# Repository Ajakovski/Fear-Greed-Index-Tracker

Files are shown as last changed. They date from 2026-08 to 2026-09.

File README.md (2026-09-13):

<div align = "center">

# A Wi-Fi powered Fear & Greed Index Tracker

<p>

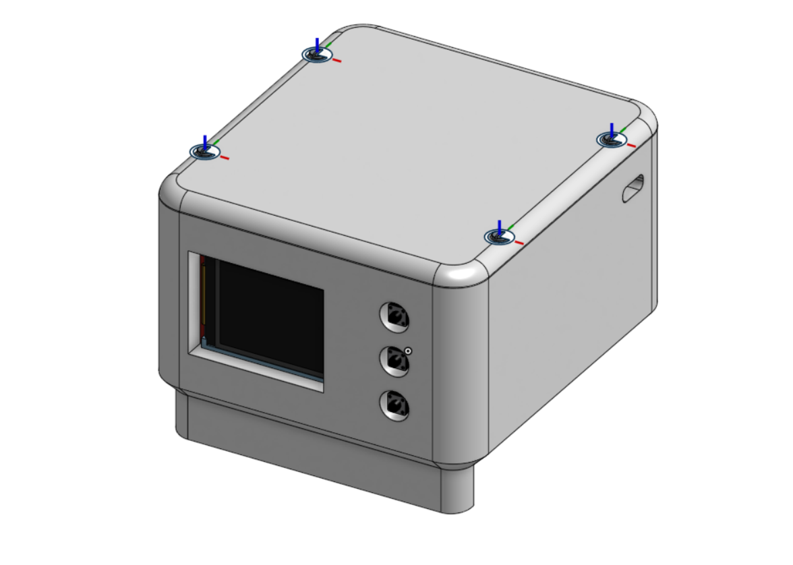
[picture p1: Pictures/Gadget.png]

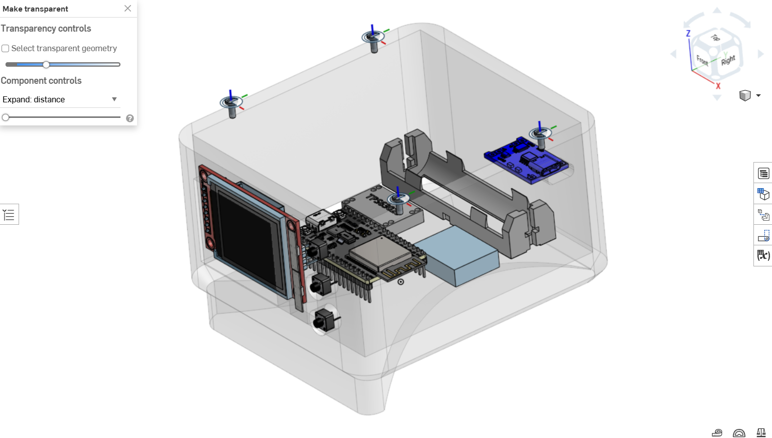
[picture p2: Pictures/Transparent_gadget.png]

</p>

### _Live tracker on your desk displaying how the market *FEELS*._

</div>

---
## Motivation

<div align = "center">

Have you ever felt overwhelmed by the sheer amount of work that you have limiting your counciousness that you **HAVE** to check the US stock market because your whole childhood lifesavings could be **GONE** thanks to **YOUR** irresponsible trading???

</div>

> _If you said yes..._

<div align = "center">

***WORRY NO MORE!!!***

------------------------------------------- ***THE FEAR & GREED INDEX TRACKER*** --------------------------------------------

</div>

**The gadget on your working desk that you did not know you ever needed.**

Always have a quick look on the current state of the market while working on something else giving you the power to intervene in the market when needed and not stress out about FOMO.

I wanted to have something long lasting on my desk that wont fail  me in the middle of the week because this project is meant to save time, not external work :)

Have the power of changing indexes based on your preference (coming in future versions)

## Overview

**Fear&Greed Index Tracker**

A portable working-desk gadget to remind you of the madness happening in the US market world. Thanks to the ESP32 WiFi integrations we can fetch data from the internet and make this cool project alive on your desk.

The information is displayed on our RGB display with the highest quality for monitoring the most popular indexes.
Also thanks to the battery management you dont have to bother charging it very often because it can last up to one week!!!

Built as an open-source hardware product - every schematic and line of firmware is available to reproduce, modify and improve so ***ENJOYYYYY***

---

## Assembly Guide

### Hardware

***A visual representation of the whole project has been given with the file:***

```bash
Hardware/Gadget.step
```

***If you dont prefer the files view you can always refer to the visual representation via [OnShape](https://cad.onshape.com/documents/b0f9f3ad3455fa4c269f5d70/w/b12c68eb17b42f73cf325935/e/728434c4884acb47f862d1fd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)***

#### 1. Order the 3D Print

Navigate to: (For 3D Model)
```bash
Hardware/3D_Printing/
```
*If multiple versions are available i recommend sticking to the newest one because i dont commit until its fully tested*

#### 2. Order the Components

I recommend sticking to the BOM file if you want to really copy the project.

```bash
Hardware/BOM.csv
```

Order all parts before starting your assembly.

#### 3. Solder the Components

Before assembling i suggest soldering everything together with flexible wires and strong solder joints so that everything stays in contact when you assemble it inside the case.

Prefer using wires without pins and soldering  on top of the ESP Devkit unless you have an extension that could be mounted onto the male pins of the ESP32.

Start with the power management components and then connect them with the ESP32 but keep the battery connection at last because that will start immediate power usage.

Then i would recommend moving onto the screen and buttons plus the RGB LED strip.

And finally finish the whole project by upgrading the hardware with passive components according to the KiCAD schematic.

Recommended tools:
- Flux
- A strong soldering iron with a fine-tip
- Tweezers
- Solder paste + hot air
- Helping hands with a magnifying glass

#### 4. Add Customized Button Layer

I havent designed button caps on purpose because i wanted to have stickers on top of of them because the button itself is supposed to be tiny with its cute clicking sound so it is up to you to design it how you want :))))

#### 5. Assemble the Enclosure

***Materials needed for assembling:***

- 4x M3 brass hot melt insert nuts
- Glue, any type just make sure to get a strong one
- 4x M3 screw
- Notice: if you dont get screws with the TFT lcd screen you will have to acquire them personally

***Steps for assembling***

The main and only part of assembling the casing is mounting the hat.
There are three steps for this:
- Align the hat on top of the casing and in the desired screw holes you have mark them in any possible way either pen, pencil or etc.
- Get the M3 brass hot melt insert nuts and with a soldering iron melt them into the casing.
- Then just screw in the M3 in there and pray for the best (just kidding everythings gonna be fine (hopefully)).

---

### Firmware Installation

#### 1. Install ESP-IDF

```bash
git clone -b v5.3.2 --recursive https://github.com/espressif/esp-idf.git ~/esp/esp-idf
cd ~/esp/esp-idf
./install.sh esp32
source ./export.sh
```
Follow the [official Espressif guide](https://docs.espressif.com/projects/esp-idf/en/stable/esp32s3/get-started/index.html) for WIndows and macOS variants.

#### 2. Clone the Repository

```bash
git clone https://github.com/Ajakovski/Fear-Greed-Index-Tracker.git
cd Fear-Greed-Index-Tracker
cd Firmware
```

#### 3. Set Target and Build

```bash
idf.py set-target esp32
idf.py build
```

#### 4. Flash the firmware

Connect via USB-C. If the board does not enter download mode automatically, hold **BOOT** and tap **EN**, then release BOOT.

```bash
# Linux
idf.py -p /dev/tty/USB0 flash

# macOS
idf.py -p /dev/cu.ubserial-XXXX flash

#Windows
idf.py -p COM3 flash
```

#### 5. Monitor Serial Output

```bash
idf.py -p /dev/ttyUSB0 monitor
```

Exit with 'Ctrl+]'.

---

## BOM

**If you are refering from the BOM.csv file please use a converter csv to table because it will be hard for you to read the documentation. And as always you can recall from my githubs BOM anytime you want**

| Designator | Function | Value / Part | Package | Qty | Price (USD) | Link |
|---|---|---|---|---|---|---|
| U1 | MCU | ESP32-WROOM-32 | Module | 1 | $4 | [AliExpress](https://www.aliexpress.com/item/1005001636295529.html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) |
| U2 | Li-Ion Charger | TP4056_USB-C | Module | 1 | $1 | [AliExpress](https://www.aliexpress.com/item/1005006169600517.html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) |
| J5 | Boost converter | TPS63020 | Module | 1 | $1 | [AliExpress](https://www.aliexpress.com/item/1005008003604371.html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) |
| J6 | Fuel Gauge | MAX17048 | Module | 1 | $13 | [AliExpress](https://www.aliexpress.com/item/1005010173459854.html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) |
| J4 | Screen | TFT RGB 128x160 | 1.8' | 1 | $9 | [AliExpress](https://www.aliexpress.com/item/33015586094.html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) |
| SW 1-3 | Buttons | Push button | tactile | 3(20) | $8 | [Aliexpress](https://www.aliexpress.com/item/1005007361046397.html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) |
| D1 | RGB LED | WS2812S | 5050 | 1m 30 IP67 | $5 | [AliExpress](https://www.aliexpress.com/item/2036819167.html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) |
| X | Resistor | 1KΩ / 10KΩ / 100Ω / 220Ω / 100KΩ | THT | 100 x 5 | $5 | [AliExpress](https://www.aliexpress.com/item/1005004675087796.html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) |
| X | Ceramic Capacitor | 100nF | THT | 100 | $1 | [AliExpress](https://www.aliexpress.com/item/1005006579533330.html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) |
| X | Polarized Capacitor | 10uF | THT | 10 | $3 | [AliExpress](https://www.aliexpress.com/item/1005006773833658.html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) |
| X | JST Pin | P2 | SH / PH / XH | 10 x 3 | $4 | [AliExpress](https://www.aliexpress.com/item/4001235017139.html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) |
| X | Brass Hot Nut | M3 | OD 4.5mm l. 9mm | 10 | $7 | [AliExpress](https://www.aliexpress.com/item/1005003582355741.html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) |
| X | Screw | M3 | 10mm length | 10 | $8 | [AliExpress](https://www.aliexpress.com/item/1005003970883424.html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) |
| *3D Printing* | $50 | with cargo | | | | | | 
| **TOTAL** | *approx. $119* | with cargo | | | | |

Thanks to the newest tariffs by our president (20% tax import on international goods) ***EVERYTHING IS COOKED WITH PRICES***

*Notice: These shipping costs are for the Balkans so if you are from the EU or USA there are high chances of having lower shipping costs*

*Notice: These are just recommendations that i have found to be secure and hopefully the cheapest option. Do your own research if you think that better deals exist on the current market depending on when you are buying them.*

---

## Features

- **Live Market Data** - Real market data for monitoring the US market
- **RGB LED Matrix** - Visual representation of the current state of the trading index
- **RGB Display** - High quality representation of the current situation about the markets
- **18650 Battery Powered** - Single Li-Ion with onboard USB-C charging
- **Deep Sleep** - power saving mode and market data retained in RTC memory across sleep cycles
- **Fuel Gauge** - Battery monitoring and safety guardrails
- **Longevity** - Battery lasts up to 30 working hours

---

## Hardware Stack

| Subsystem | Component | Description |
|---|---|---|
| MCU | ESP32-WROOM-32 | 8MB Flash, None PSRAM, Xtensa LX6 dual-core |
| LED Strip| WS2812S Strip | Addressable LED strip |
| Display | 128x160 TFT 1.8' | SPI Interface |
| Battery | Li-Ion 18650 3600mAh battery | |
| Charger | TP4056 w. DWA01A+FS8205A | Single-cell Li-ion, USB-C input, battery protection |
| 3.3V Rail | TPS63020 | Buck-Boost converter |
| Fuel Gauge | MAX17048 | Battery measure, sate of charge estimation |

---

## KiCAD Design

***Refer to the PDF file for better overview*** [PDF](Pictures/Schematic.pdf)

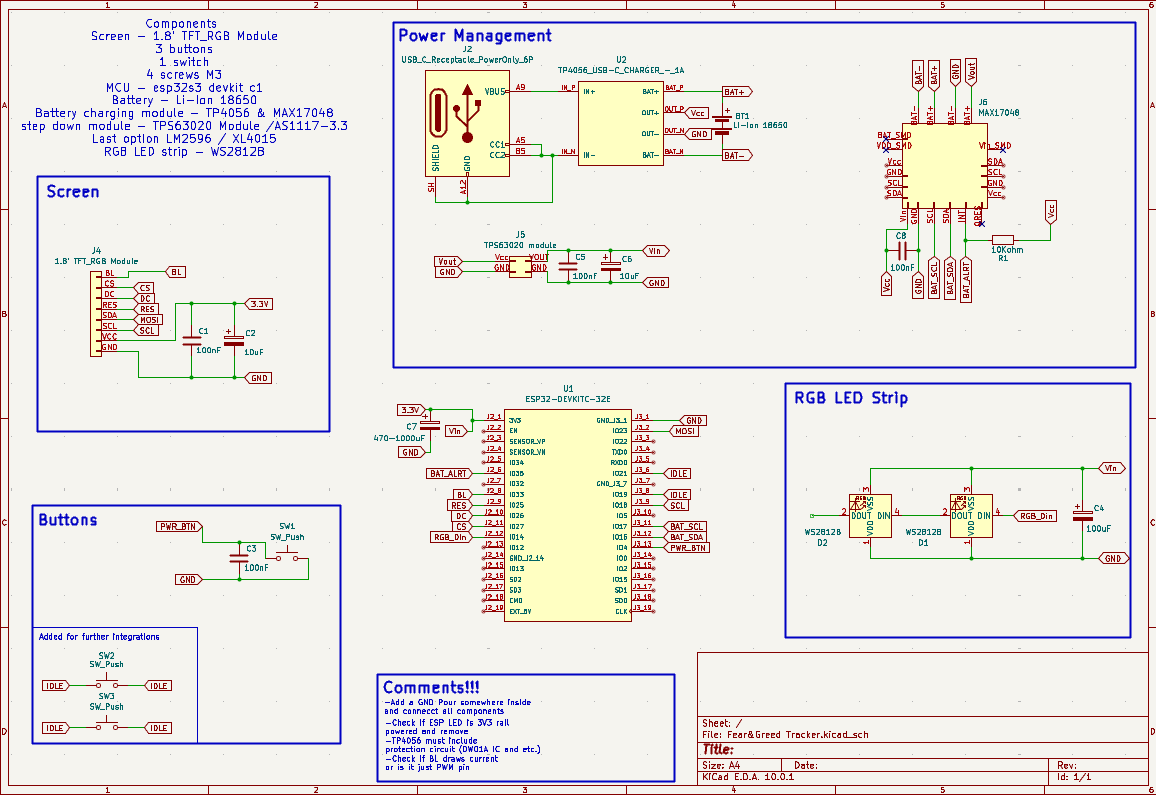
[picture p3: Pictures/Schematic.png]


---

## Hardware Pinout

| Signal | ESP32-WROOM-32 GPIO | Goes to |
|---|---|---|
| PIN_TFT_SCLK | 18 | TFT SCL |
| PIN_TFT_MOSI | 23 | TFT MOSI |
| PIN_TFT_CS | 27 | TFT CS |
| PIN_TFT_DC | 26 | TFT DC |
| PIN_TFT_RST | 25 | TFT RST |
| PIN_TFT_BL | 33 | TFT BL |
| PIN_BTN_POWER | 4 | Power Button |
| PIN_BTN_NAV1 | 19 | Nav1 Button |
| PIN_BTN_NAV2 | 21 | Nav2 Button |
| PIN_FG_SDA | 16 | Fuel gauge SDA |
| PIN_FG_SCL | 17 | Fuel gauge SCL |
| PIN_FG_ALRT | 35 | Fuel gauge alert |
| PIN_RGB_LED_DIN | 14 | RGB LED Strip |

---

## Enclosure

- Simple to assemble
- Firm and high-quality material for premium feel
- The board is made out of PLA
- 10% infill on the whole 3D model
- Tolerances applied accordingly

*Feel free to change the material/in-fill according to your desire and budget approach*

---

## Firmware features:
- FreeRTOS machine
- Deep sleep with RTC memory retention
- Wi-Fi communication
- Power saving modes beyond deep sleep

```bash
Fear_Greed_Index/
|--- Firmware/
|    |--- main/
|    |    |--- main.c
|    |    |--- CMakeLists.txt
|    |    |--- Kconfig.projbuild
|    |    |--- idf_component.yml
|    |    |--- pins.h
|    |    |--- wifi_mgr.h
|    |    |--- wifi_mgr.c
|    |    |--- buttons.h
|    |    |--- buttons.c
|    |    |--- fuelgauge.h
|    |    |--- fuelgauge.c
|    |    |--- data_fetch.c
|    |    |--- data_fetch.h
|    |    |--- display.h
|    |    |--- display.c
|    |    |--- rgb_led.h
|    |    |--- rgb_led.c
|    |--- CMakeLists.txt
|    |--- sdkconfig
|    |--- .gitignore
|    |--- sdkconfig.old
|    |--- dependencies.lock
|    |--- build/
|    |--- managed_components/
|    |--- .vscode/
|    |    |--- c_cpp_properties.json
|    |    |--- settings.json
|    |    |--- launch.json
|    |--- debugging/
|    |    |--- tasks.json
|--- Hardware/
|    |--- 3D_Printing/
|    |--- KiCad/
|    |--- BOM.csv
|--- Pictures/
|--- LICENSE
|--- README.md
```

## Current Status

- [X] Initial Concept
- [X] Layout Finalized
- [X] Schematic
- [X] Firmware
- [X] Deep Sleep + RTC Retention
- [X] Battery Monitoring
- [X] 3D Model
- [X] Final BOM
- [X] Initial 1.0V
- [ ] Soldering
- [ ] Final Build
- [ ] Upgraded Firmware
- [ ] Upgraded Schematic

---

## Contributing

Contributions, suggestions and feedback are welcome!!!

If you'd like to improve Fear & Greed Index Tracker:

1. Fork or clone the repository
```bash
git clone https:/github.com/Ajakovski/Fear-Greed-Index-Tracker.git
cd Fear-Greed-Index-Tracker
```

2. Create your feature branch (if forked)
3. Commit your changes
4. Open a pull request

For significant hardware changes, open an issue first to discuss before investing time in schematic work. Any new implementation must be self-contained in its own `.c`/`.h` pair.

If you build one, open an issue with photos.

---

## Creator

#### Ajakovski aka. Marsovac

Hey my name is Andrej and im from Macedonia, Kratovo. Im 18 years old and i really enjoy making cool projects which are all posted on my github.

Main focus while building the project:
- Individual planning and structuring
- Something from nothing
- Embedded systems engineering
- Schematic construction with core electrical concepts
- Make something useful
- Save me from phone screentime
- Market awareness

---

## License

This project is licensed under the **MIT License** - see [LICENSE](LICENSE) for full terms.

API used: AlphaVintage - [LINK](https://www.alphavantage.co/)

---

## Disclaimer
_This Device displays market sentiment data for informational purposses. It is not financial advice whatsoever._

<div align="center">

### Fear & Greed Index Tracker

#### _At any time prepared for disasters._

</div>

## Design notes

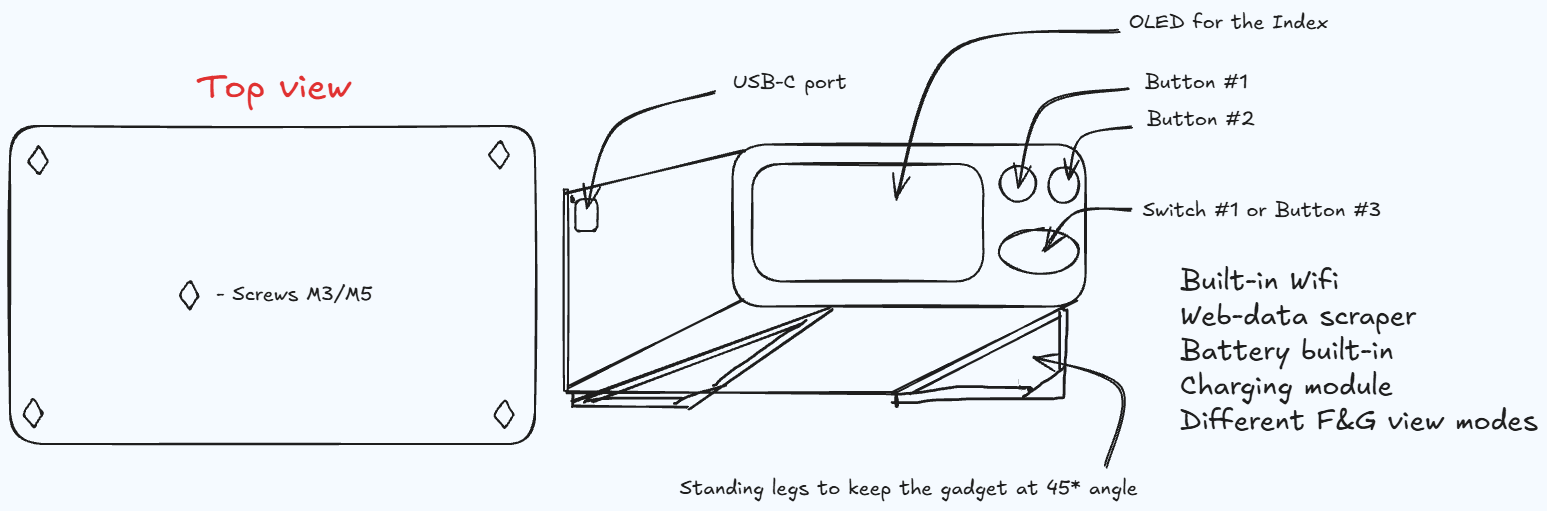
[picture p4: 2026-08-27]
Pictures/Fear&Greed _Picture_Drawing.png

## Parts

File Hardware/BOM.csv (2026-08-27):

Designator | Function | Value / Part | Package | Qty | Price (USD) | Link
U1 | MCU | ESP32WROOM32 | Module | 1 | 4$ | [AliExpress](https://www.aliexpress.com/item/1005001636295529.html?scm_id=1007.40050.354490.0&scm-url=1007.40050.354490.0
U2 | LiIon Charger | TP4056 USBC | Module | 1 | 1$ | [AliExpress](https://www.aliexpress.com/item/1005006169600517.html?scm_id=1007.40050.354490.0&scm-url=1007.40050.354490.0
J3 | BuckBoost Converter | TPS63020 | Module | 1 | 1$ | [AliExpress](https://www.aliexpress.com/item/1005008003604371.html?curPageLogUid=DzkogbJnKaCp
J6 | Fuel Gauge | MAX17048 | Module | 1 | 13$ | [AliExpress](https://www.aliexpress.com/item/1005010173459854.html?curPageLogUid=Yf0c9ARxOWht
J4 | Screen | TFT RGB 128x160 | 1.8' | 1 | 9$ | [AliExpress](https://www.aliexpress.com/item/33015586094.html?scm_id=1007.40050.354490.0&scm-url=1007.40050.354490.0
SW x3 | Buttons | Push Button | tactile | 20 | 8$ | [AliExpress](https://www.aliexpress.com/item/1005007361046397.html?scm_id=1007.40050.354490.0&scm-url=1007.40050.354490.0
D1 | RGB LED | WB2812S | 5050 | 1m 30 IP67 | 5$ | [AliExpress](https://www.aliexpress.com/item/2036819167.html?scm_id=1007.40050.354490.0&scm-url=1007.40050.354490.0
X | Resistor | 1KΩ / 10KΩ / 100Ω / 220Ω / 100KΩ | THT | 100 x 5 | 5$ | [AliExpress](https://www.aliexpress.com/item/1005004675087796.html?scm_id=1007.40050.354490.0&scm-url=1007.40050.354490.0
X | Ceramic Capacitor | 100nF | THT | 100 | 1$ | [AliExpress](https://www.aliexpress.com/item/1005006579533330.html?scm_id=1007.40050.354490.0&scm-url=1007.40050.354490.0
X | Polarized Capacitor | 10uF | THT | 10 | 3$ | [AliExpress](https://www.aliexpress.com/item/1005006773833658.html?curPageLogUid=IloixCtXNMcv
X | JST Pin | P2 | SH / PH / XH | 10 x 3 | 4$ | [AliExpress](https://www.aliexpress.com/item/4001235017139.html?curPageLogUid=DicSMvRtoGFK
X | Brass Hot Nut | M3 | OD 4.5mm l. 9mm | 10 | 7$ | [AliExpress](https://www.aliexpress.com/item/1005003582355741.html?scm_id=1007.40050.354490.0&scm-url=1007.40050.354490.0
X | Screw | M3 | 10mm length | 10 | 8$ | [AliExpress](https://www.aliexpress.com/item/1005003970883424.html?curPageLogUid=znGLE1nIk6yr
3D Printing | 50$ | with cargo
TOTAL | approx. 119$ | with cargo

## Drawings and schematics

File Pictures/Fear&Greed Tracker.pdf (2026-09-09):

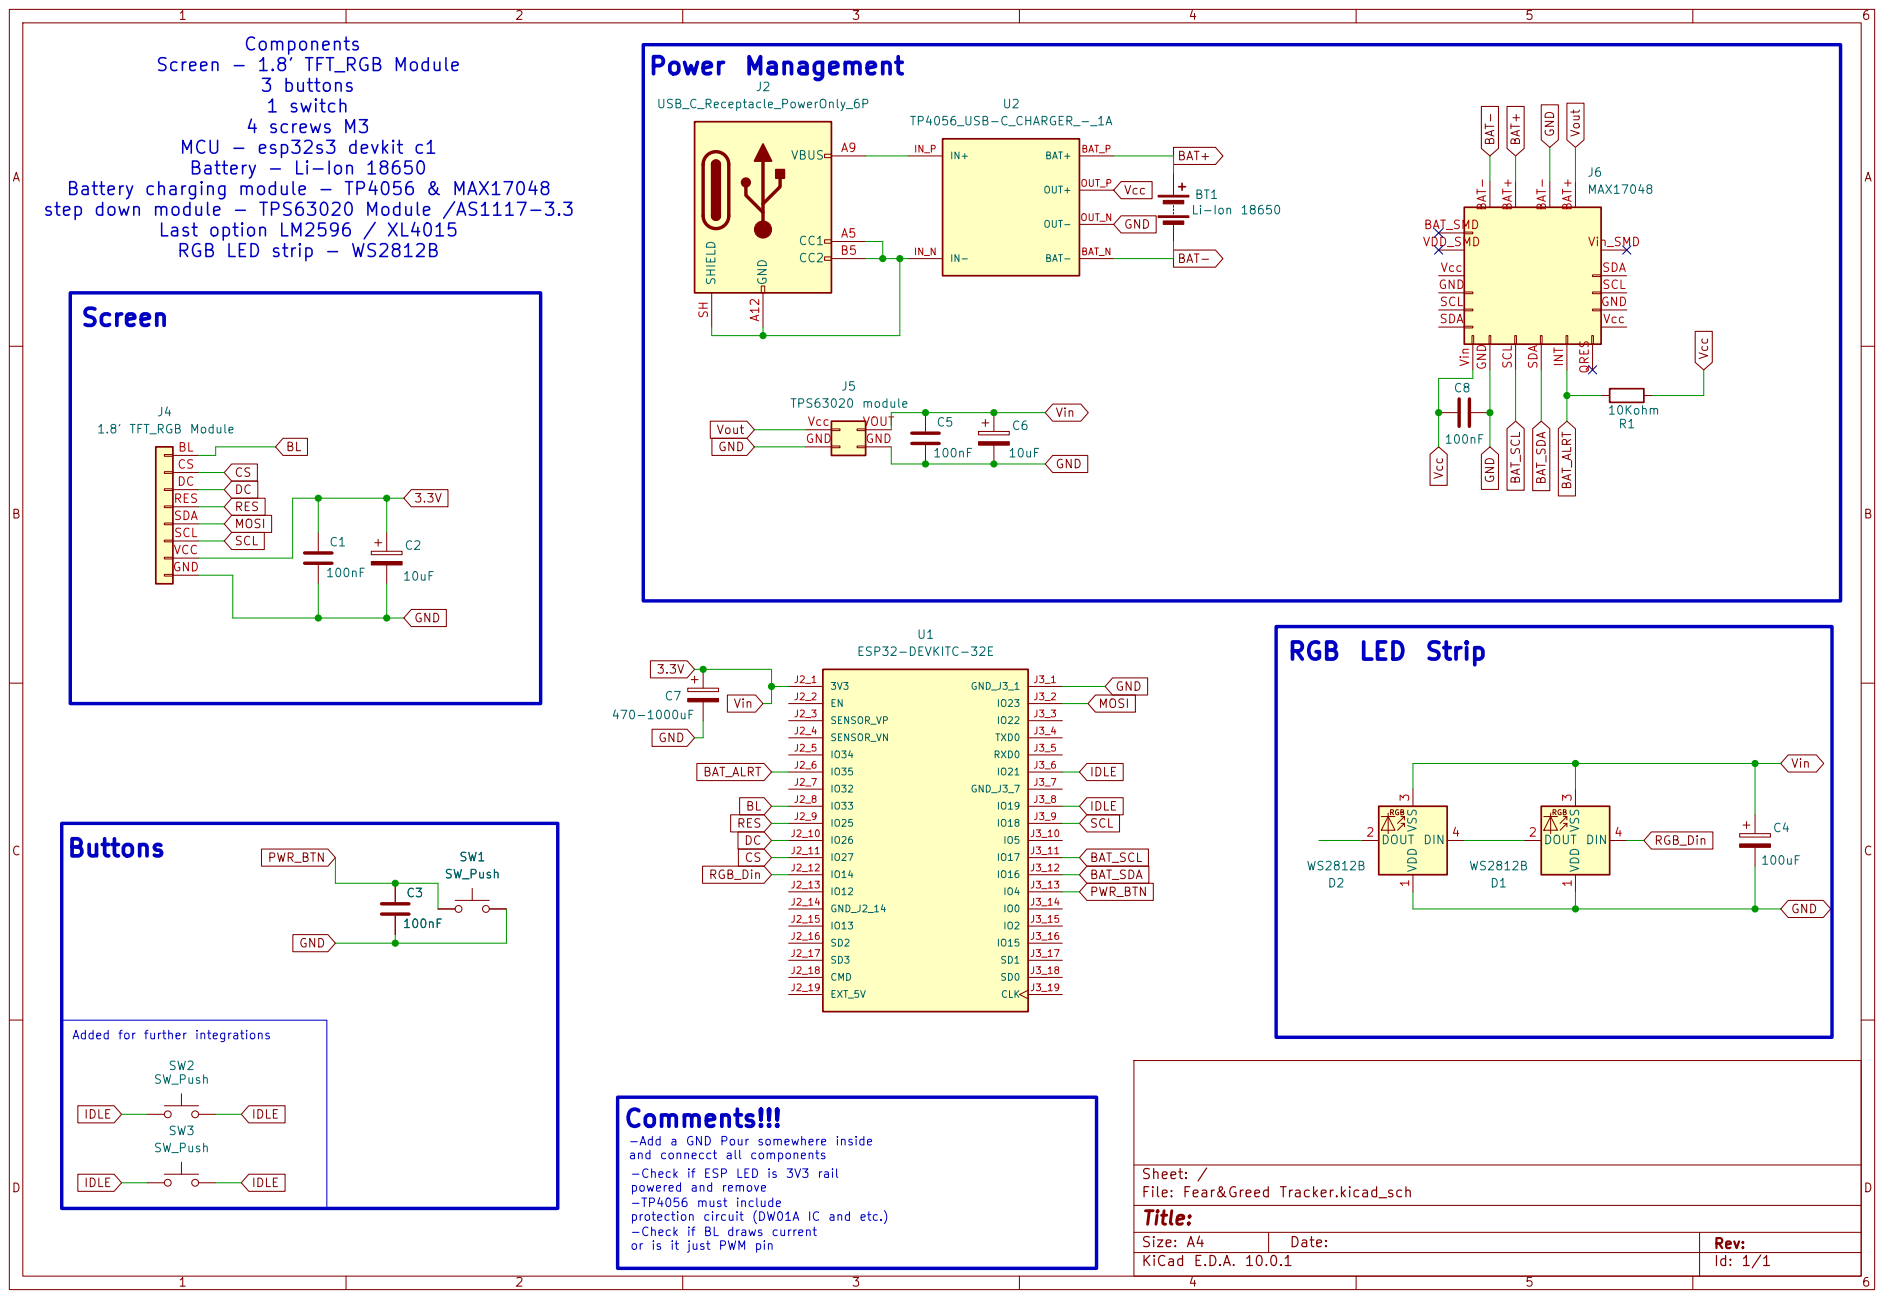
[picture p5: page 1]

Battery charging module - TP4056 & MAX17048
step down module - TPS63020 Module /AS1117-3.3

BL RGB_DinCS RES -Check if BL draws current or is it just PWM pin

SW_Push
-TP4056 must include protection circuit (DW01A IC and etc.) -Check if ESP LED is 3V3 rail powered and remove C3

Added for further integrations

Comments!!! -Add a GND Pour somewhere inside and connecct all components

Sheet: /
File: Fear&Greed Tracker.kicad_sch
Title:

Size: A4 | Rev:
KiCad E.D.A. 10.0.1 | Id: 1/1

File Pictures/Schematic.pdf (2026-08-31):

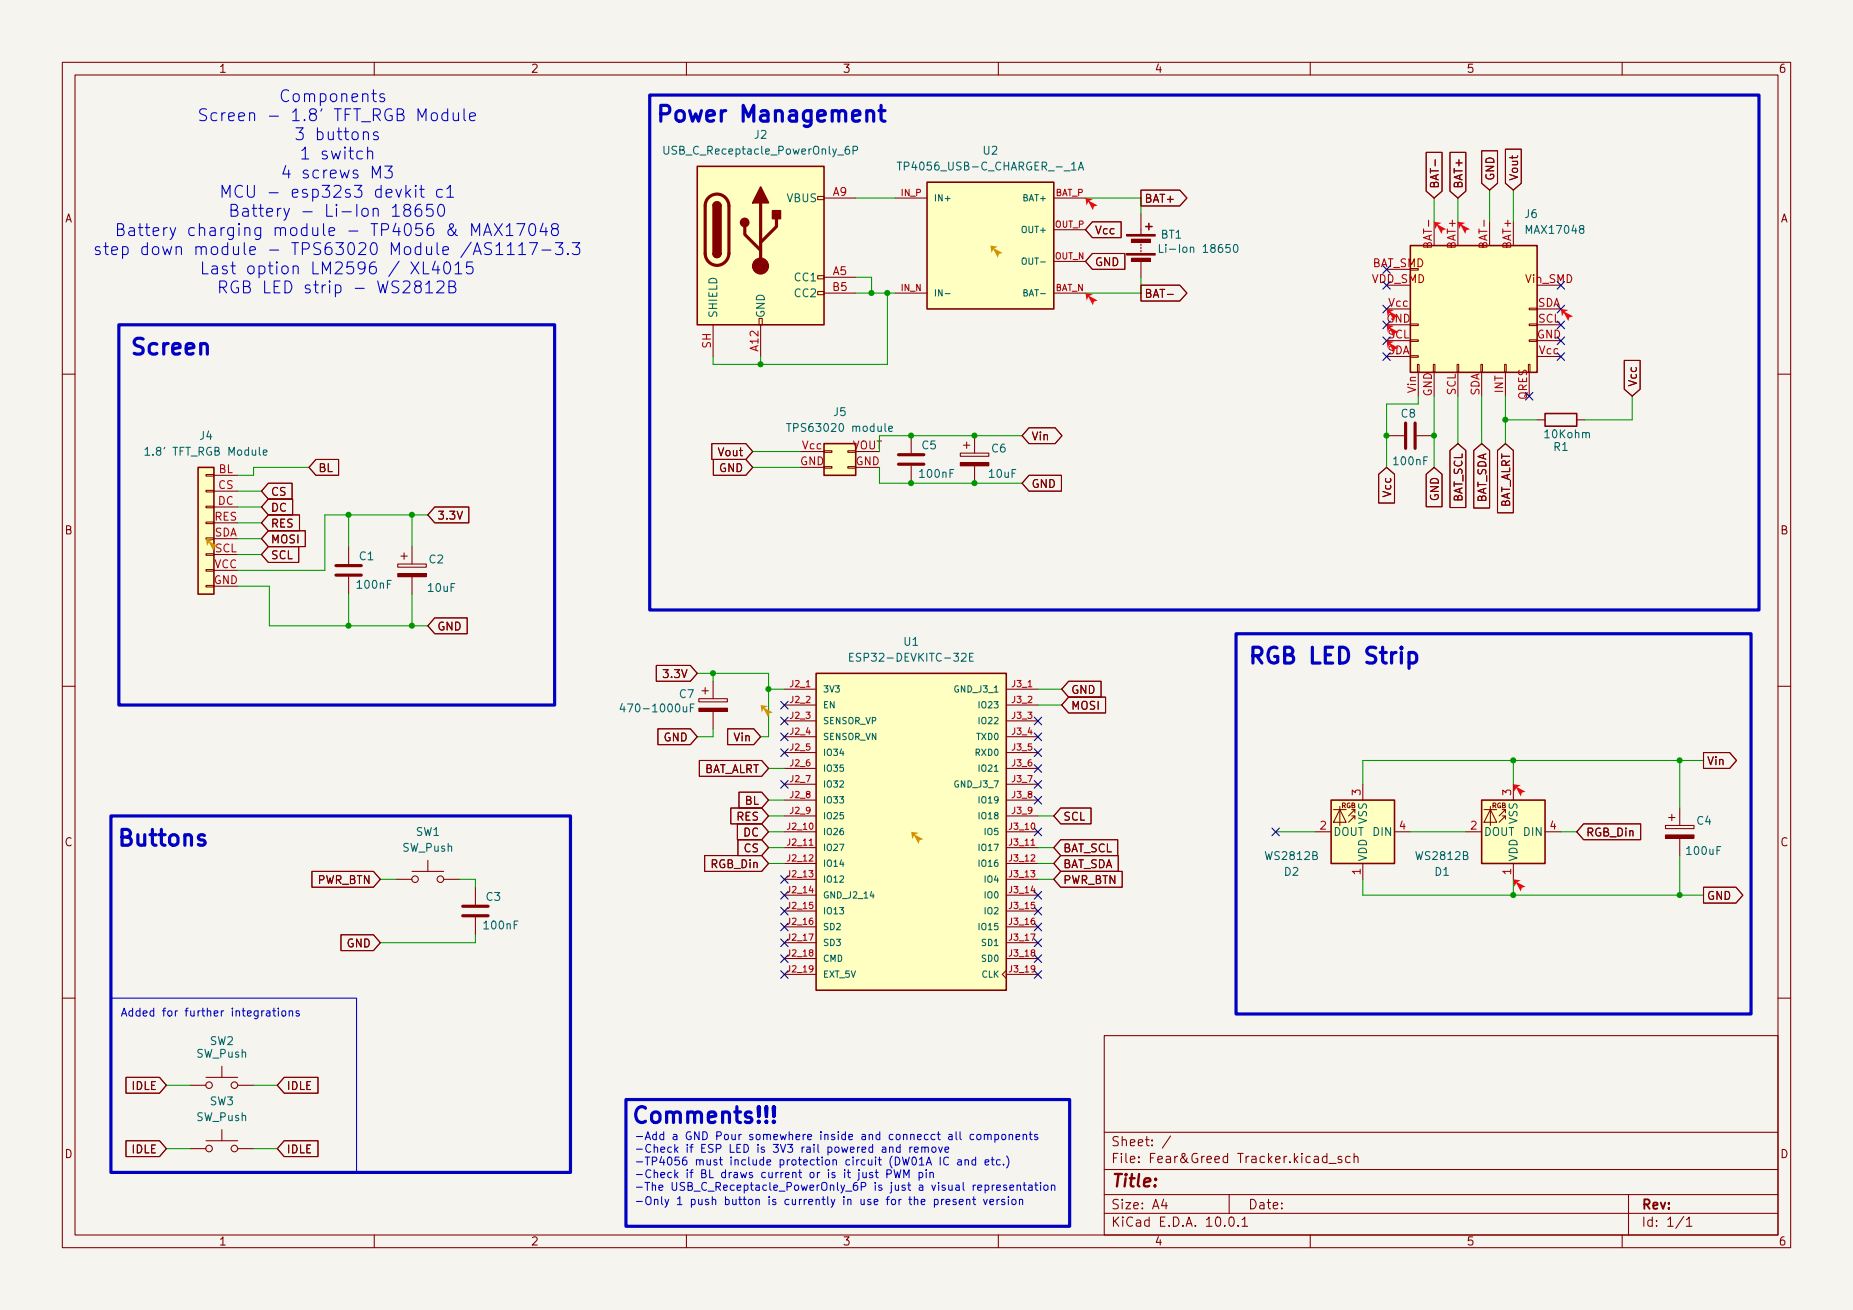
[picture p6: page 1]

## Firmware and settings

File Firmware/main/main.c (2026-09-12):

#include "wifi_mgr.h"
#include "buttons.h"
#include "data_fetch.h"
#include "display.h"
#include "fuelgauge.h"
#include "rgb_led.h"
#include "pins.h"
#include "nvs_flash.h"
#include "esp_log.h"
#include "esp_sleep.h"
#include "esp_wifi.h"
#include "driver/rtc_io.h"
#include "driver/gpio.h"
#include "freertos/FreeRTOS.h"
#include "freertos/task.h"
#include "freertos/queue.h"

static const char *TAG="main";
static QueueHandle_t s_btn_queue;

static void enter_deep_sleep(void){
    ESP_LOGI(TAG,"entering deep sleep");
    rgb_led_off();
    rtc_gpio_pullup_en(PIN_BTN_POWER);
    rtc_gpio_pulldown_dis(PIN_BTN_POWER);
    esp_sleep_enable_ext0_wakeup(PIN_BTN_POWER,0);
    esp_deep_sleep_start();
}

static void enter_light_sleep(void){
    ESP_LOGI((TAG,"entering light sleep"));
    display_set_backlight(0);
    rgb_led_off();
    esp_wifi_stop();

    gpio_wakeup_enable(PIN_BTN_POWER, GPIO_INTR_LOW_LEVEL);
    esp_sleep_enable_gpio_wakeup();
    esp_light_sleep_start();
    esp_wifi_start();
    display_set_backlight(255);
    display_refresh_led();
    ESP_LOGI(TAG,"woke from light sleep"); 
}

static void fuelgauge_task(void *arg){
    fuelgauge_init();
    while(1){
        float voltage;
        uint8_t percent;
        if(fuelgauge_read(&voltage,&percent)==ESP_OK){
            display_msg_t msg={.type=DISPLAY_MSG_BATTERY_PCT, .battery_pct=percent};
            display_post_msg(&msg);
        }
        vTaskDelay(pdMS_TO_TICKS(60000));}}

void main(void){
    esp_err_t ret=nvs_flash_init();
    if(ret==ESP_ERR_NVS_NO_FREE_PAGES|| ret==ESP_ERR_NVS_NEW_VERSION_FOUND){
        ESP_ERROR_CHECK(nvs_flash_erase());
        ret=nvs_flash_init();       
    }
    ESP_ERROR_CHECK(ret);
    ESP_ERROR_CHECK(wifi_mgr_init());
    ESP_ERROR_CHECK(display_init());
    ESP_ERROR_CHECK(data_fetch_init());
    xTaskCreate(fuelgauge_task,"fuelgauge",3072,NULL,3,NULL);
    s_btn_queue=xQueueCreate(4,sizeof(button_event_t));
    ESP_ERROR_CHECK(buttons_init(s_btn_queue));
    ESP_LOGI(TAG,"waiting for wifi...");
    if(wifi_mgr_wait_connected(pdMS_TO_TICKS(15000))){
        ESP_LOGI(TAG,"wifi connected");
    }else{
        ESP_LOGW(TAG,"still waiting, it'll keep retrying in the background");
    }
    button_event_t evt;
    while(1){
        if(xQueueReceive(s_btn_queue,&evt,portMAX_DELAY)==pdTRUE){
            switch(evt){
                case BTN_EVT_NAV_NEXT:{
                    display_msg_t msg={.type=DISPLAY_MSG_NAV_NEXT};
                    display_post_msg(&msg);
                    break;
                }
                case BTN_EVT_NAV_PREV:{
                    display_msg_t msg={.type=DISPLAY_MSG_NAV_PREV};
                    display_post_msg(&msg);
                    break;
                }
                case BTN_EVT_SLEEP_DEEP;
                    enter_deep_sleep();break;
                case BTN_EVT_SLEEP_LIGHT;
                enter_light_sleep();
                break;
            }
        }
    }
}

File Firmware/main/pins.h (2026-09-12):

#pragma once
#define PIN_TFT_SCLK 18
#define PIN_TFT_MOSI 23
#define PIN_TFT_CS 27
#define PIN_TFT_DC 26
#define PIN_TFT_RST 25
#define PIN_TFT_BL 33

#define PIN_BTN_POWER 4
#define PIN_BTN_NAV1 19
#define PIN_BTN_NAV2 21

#define PIN_FG_SDA 16
#define PIN_FG_SCL 17
#define PIN_FG_ALRT 35

#define PIN_RGB_LED_DIN 14

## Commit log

2026-08-26 Revise README for clarity and detail
    Updated README to enhance project description and assembly instructions.
2026-08-27 Folder setup
    [Fear&Greed Tracker.kicad_pcb, Fear&Greed Tracker.kicad_sch]
2026-08-27 Revise BOM entries and total cost in README
    Updated component details and prices in the BOM section of the README.
2026-08-27 Added BOM.csv
    [BOM.csv]
2026-08-27 Revise BOM.csv with new components and pricing
    Updated BOM.csv to reflect new component entries and prices.
    [BOM.csv]
2026-08-31 Coding so far...
    Had to commit prematurely because im switching to code from my laptop from tomorrow
2026-09-09 Uploaded BOM, CAD and Pictures
    [BOM.csv, Fear&Greed Tracker.kicad_pcb, Fear&Greed Tracker.kicad_sch]
2026-09-09 3D Printing files
2026-09-12 Full Assembly Step
